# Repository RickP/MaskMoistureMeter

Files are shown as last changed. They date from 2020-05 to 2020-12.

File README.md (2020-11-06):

# MaskMoistureMeter

## About this project

A simple device that measures the moisture of face masks. It uses a 555 timer to measure the resistance of cloth.

If the mask is dry, it lights up a green LED. If the mask is moist it blinks a red LED and also beeps with a piezo buzzer.
The faster is blinks and the higher the beepers pitch the more moisture is in your mask.

Replace and/or wash moist masks immediately as wearing a wet mask is dangerous to your health.

The electronics was designed in KiCad and has all information tor order it assembled from JLCPCB.

## Project files

- case: The case as a step and stl file
- fabrication: Gerbers, bom and pick and place files, made according to the JLCPCB free SMT assembly specs
- images: Some images of the PCB, assembled PCB and the case
- pcb: KiCad project files

## PCB specs

- 2 layers FR4
- EIG finish recommended so the sensor area doesn't oxidize
- Board thickness 1mm - otherwise it won't fit the included case

## Parts

### BT1
Battery holder for a CR2032 coin cell. Alternative to LCSC part: Keystone 1060.

### BZ1
The buzzer. Murata PKMCS0909E4000-R1 - can be left out for LED indication only.

### C1 and C2
100nf 0603 capacitor. Use any one with at least 5% tolerance and 6.3V voltage rating.

### D1 and D2
0805 LED in green (D1) and red (D2). Use LEDs with a forward voltage of under 2.8V.

### R1 and R2
0603 resistor with about 150 ohm. Adjust to tune the brightness of your LEDs.

### R3
0603 resistor with 1k.

### SW1
5.1x5.1mm SMD push button with gullwing pins and a height of 3 to 3.5mm.
Alternatives to the LCSC part: Würth 430451035836 or C&K KSC341GLFS

### U1
555 timer IC in 8-SOIC package that works at 2V.
You can use: TLC555CDR, TLC555IDR, TLC555QDR or TLC555CD

## Video Demo

[See it in action here](https://www.youtube.com/watch?v=zS53NGnmHDQ)

## Assembled device in case

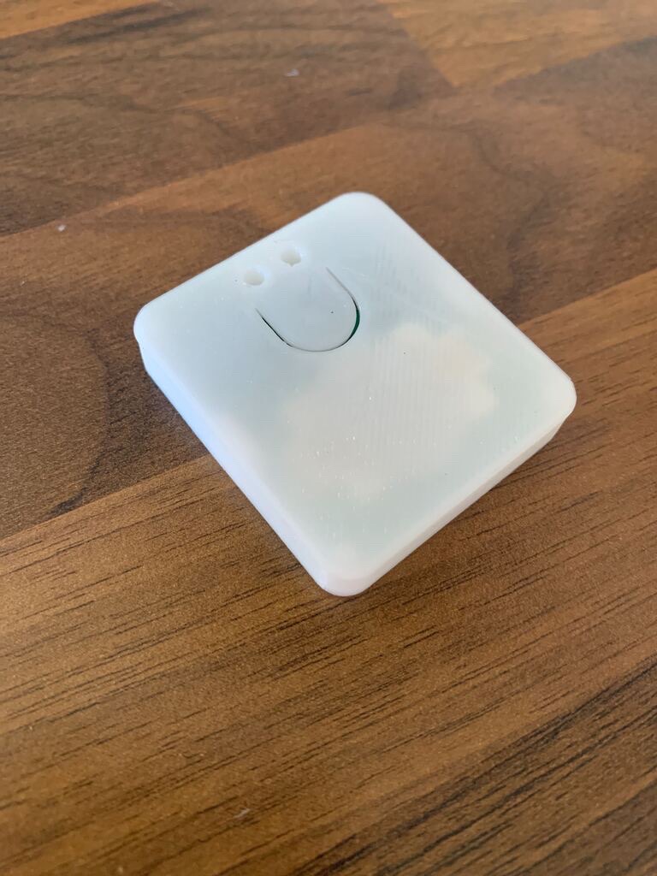
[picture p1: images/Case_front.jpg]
Meter in case


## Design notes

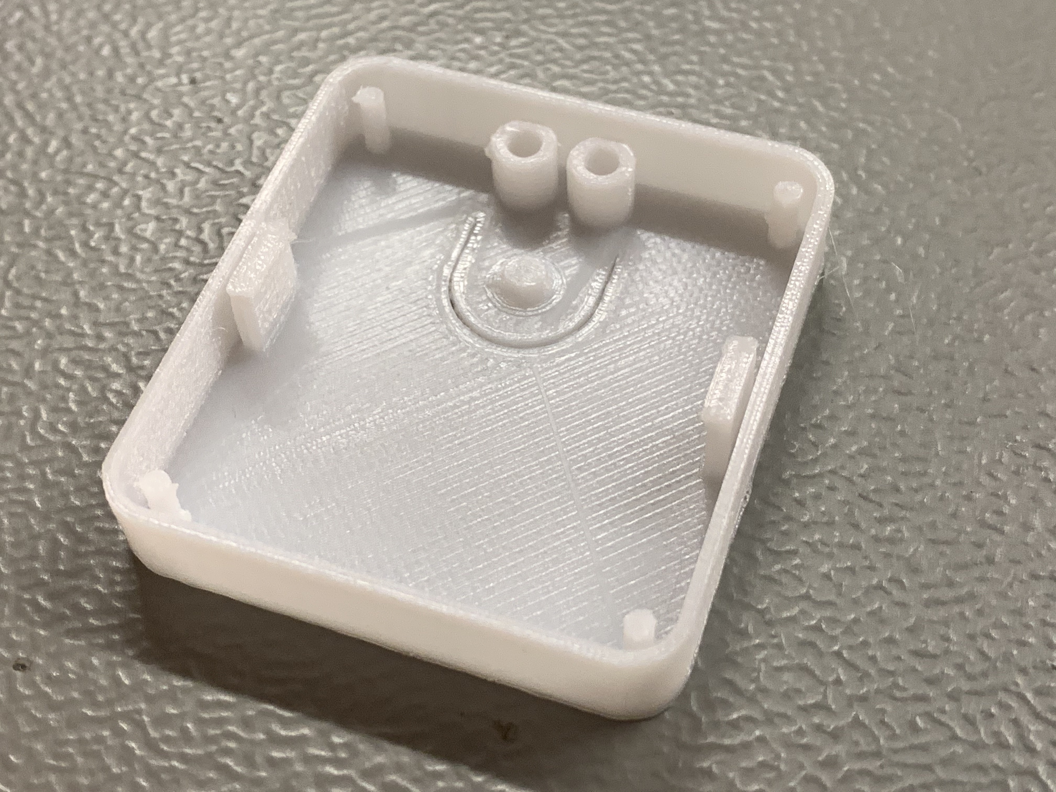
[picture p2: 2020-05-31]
images/Case_back.jpg

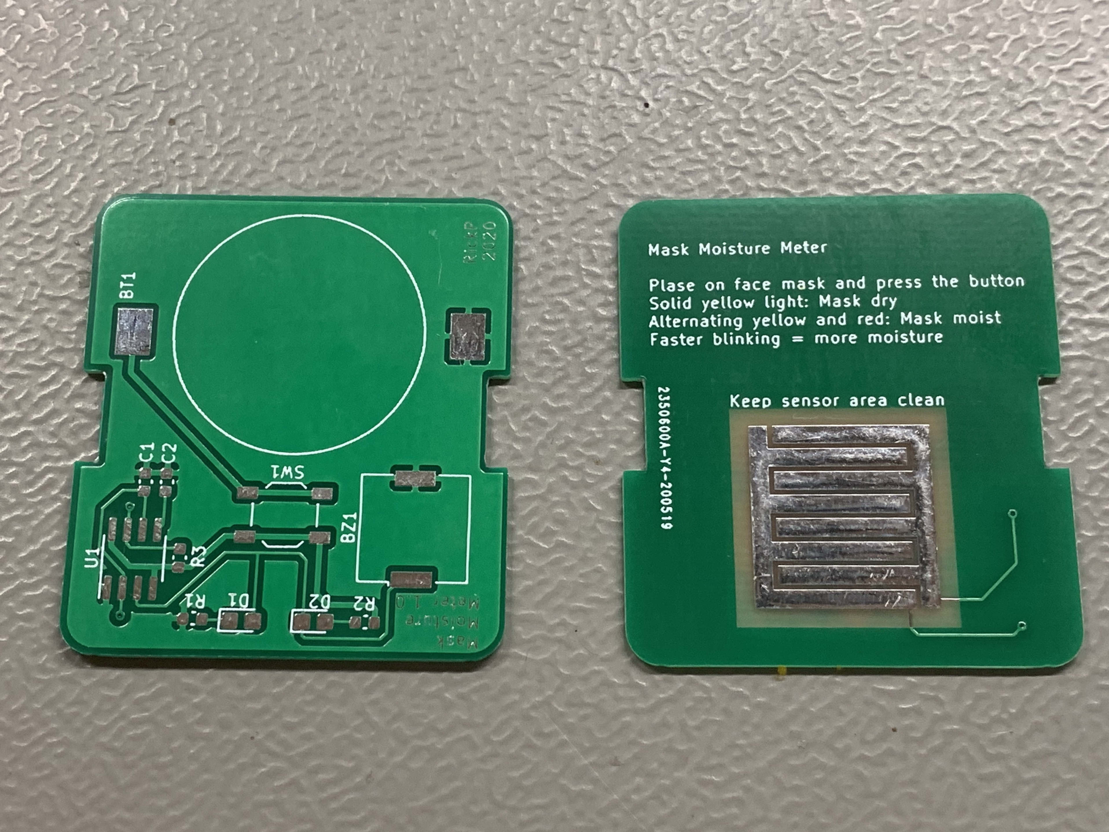
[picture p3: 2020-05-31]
images/PCB_front_back.jpg

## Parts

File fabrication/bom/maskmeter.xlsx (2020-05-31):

maskmeter
Comment | Designator | Footprint | LCSC
Battery_Cell | BT1 | Battery:BatteryHolder_Keystone_1060_1x2032 | C70377
Buzzer | BZ1 | Buzzer_Beeper:Buzzer_Murata_PKMCS0909E4000-R1 | C391035
0.1uF | C2,C1 | Capacitor_SMD:C_0603_1608Metric | C14663
GREEN LED | D1 | LED_SMD:LED_0805_2012Metric_Castellated | C375452
RED LED | D2 | LED_SMD:LED_0805_2012Metric_Castellated | C84256
R150 | R1,R2 | Resistor_SMD:R_0603_1608Metric | C22808
1k | R3 | Resistor_SMD:R_0603_1608Metric | C21190
SW_Push | SW1 | Button_Switch_SMD:SW_SPST_TL3342 | C318886
TLC555IDR | U1 | Package_SO:SOIC-8_3.9x4.9mm_P1.27mm | C6987

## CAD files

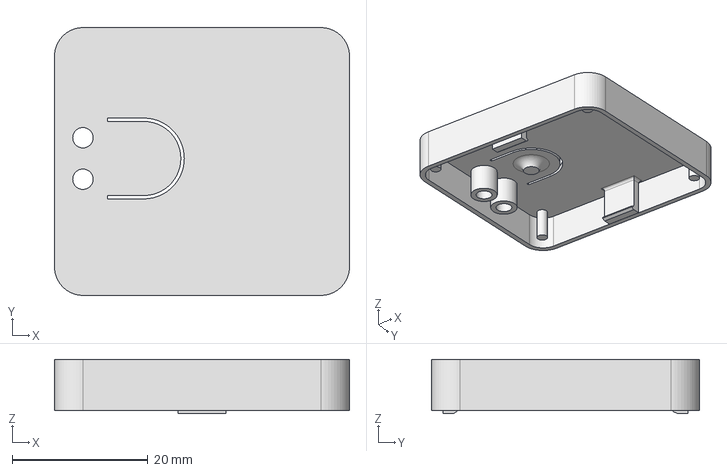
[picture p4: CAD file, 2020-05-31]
case/maskmeter-case.step
43.4 x 39.4 x 8.00 mm

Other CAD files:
case/maskmeter-case.stl

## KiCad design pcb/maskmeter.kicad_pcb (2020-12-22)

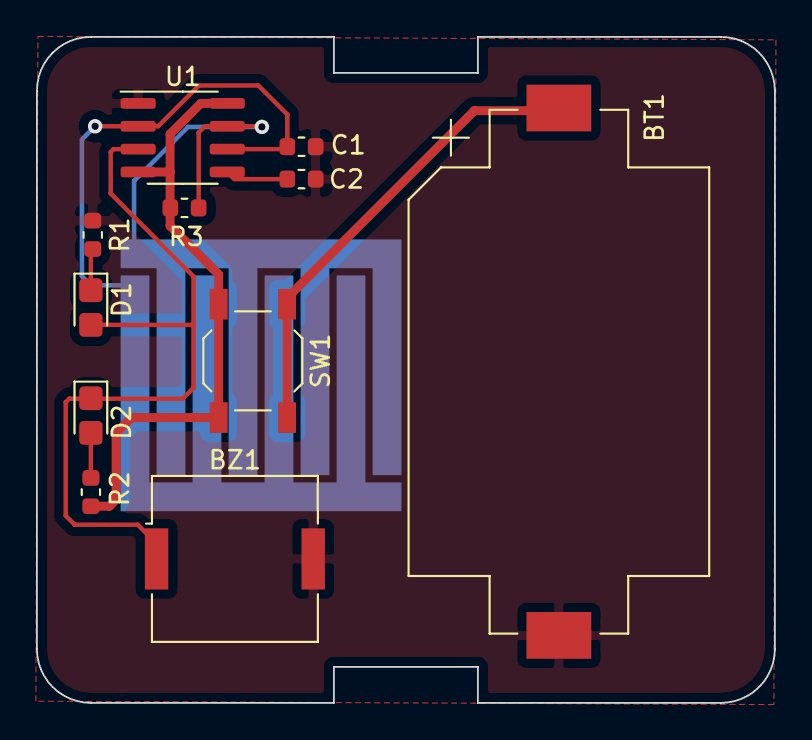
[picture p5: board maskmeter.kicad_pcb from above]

Board: 2 copper layers, 41.0 x 37.0 mm, 12 parts (1 on the bottom side), 9 nets.

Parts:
BT1: Battery_Cell; BatteryHolder_Keystone_1060_1x2032
BZ1: Buzzer; Buzzer_Murata_PKMCS0909E4000-R1
C1, C2: 0.1uF; C_0603_1608Metric
D1: YELLOW; LED_0805_2012Metric_Castellated
D2: RED; LED_0805_2012Metric_Castellated
R1, R2: R75; R_0603_1608Metric
R3: 1k; R_0603_1608Metric
R4: R_PCB; PCB_Resistance_Pad
SW1: SW_Push; SW_SPST_TL3342
U1: TLC555IDR; SOIC-8_3.9x4.9mm_P1.27mm

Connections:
GND: BT1.2, BZ1.2, C1.1, C2.2, R1.2, U1.1
unnamed: BT1.1, SW1.1
unnamed: BZ1.1, D1.2, D2.1, U1.3
unnamed: C1.2, R4.1, U1.2, U1.6
unnamed: C2.1, U1.5
unnamed: D1.1, R1.1
unnamed: D2.2, R2.2
unnamed: R3.2, R4.2, U1.7
VCC: R2.1, R3.1, SW1.2, U1.4, U1.8

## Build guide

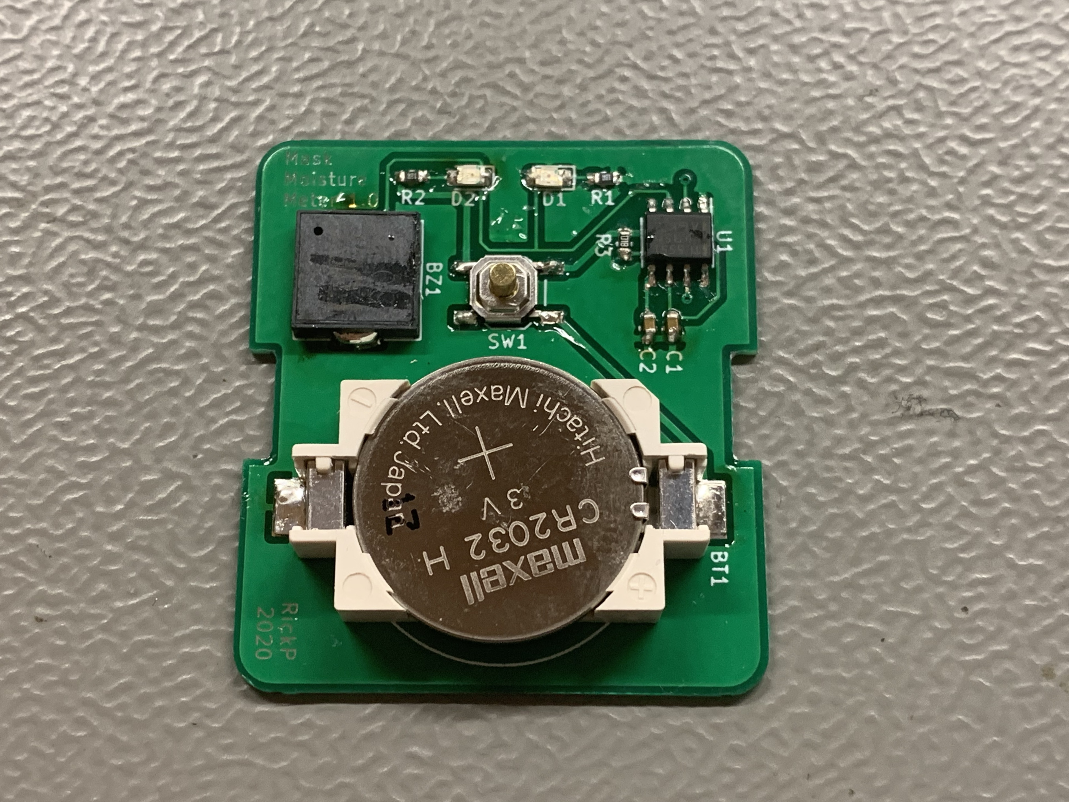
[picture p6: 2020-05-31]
images/PCB_assembled.jpg

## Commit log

2020-05-31 Updated battery holder
    [maskmeter-B_Cu.gbr, maskmeter-B_Mask.gbr, maskmeter-B_Paste.gbr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]
2020-05-31 Reorganized files
    [maskmeter-B_Cu.gbr, maskmeter-B_Mask.gbr, maskmeter-B_Paste.gbr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]
2020-05-31 Added fabrication files
    [maskmeter-B_Cu.gbr, maskmeter-B_Mask.gbr, maskmeter-B_Paste.gbr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]
2020-05-31 Added case
    [maskmeter-case.step, maskmeter-case.stl]
2020-05-31 Updates gerbers
    [maskmeter-B_Cu.gbr, maskmeter-B_Mask.gbr, maskmeter-B_Paste.gbr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]
2020-05-31 Changed resitors and green LED
    [maskmeter.kicad_pcb, maskmeter.sch, maskmeter.xlsx]
2020-11-06 Set PCB thickness to 1mm
    [maskmeter.kicad_pcb]
2020-12-22 Revert "Set PCB thickness to 1mm"
    This reverts commit 019fabce52c92cc1307a1fe131da5ab49f218db2.
    [maskmeter.kicad_pcb]
2020-12-22 Redid last commit in Kicad 5 (instead of nightly)
    [maskmeter.kicad_pcb]
